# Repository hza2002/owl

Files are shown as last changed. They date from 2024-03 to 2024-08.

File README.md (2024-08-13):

# Owl
**Owl**, an acronym for **Orthogonal Wireless Layout**, combines the ergonomic freedom of wireless connectivity with a split keyboard design influenced by [Lily58](https://github.com/kata0510/Lily58), [Corne](https://github.com/foostan/crkbd), [Sofle](https://github.com/josefadamcik/SofleKeyboard) and [Torn](https://github.com/rtitmuss/torn) keyboards.
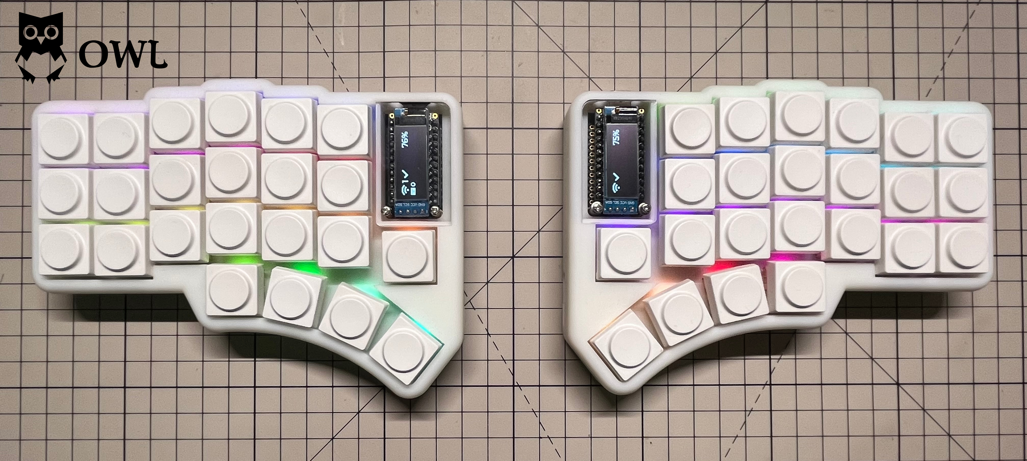
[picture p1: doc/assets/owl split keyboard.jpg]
Owl Split Keyboard

## Feature
- Owl uses **Pro Micro** Interconnect small controller board, which means easy for Maintenance and replacemen. And supports a variety of boards including [nice!nano](https://nicekeyboards.com/nice-nano) and [nrfmicro](https://github.com/joric/nrfmicro/) (I **have not tried yet**, but theoretically feasible).
- Low latency wireless, supported by [ZMK](https://github.com/zmkfirmware/zmk).
- Gorgeous **RGB** lighting effects.
- Two multifunctional **OLED** screens that can display keyboard battery level and connection status.
- Split keyboard conforms to **ergonomics**.
- A total of two PCBs compatible with Cherry MX switches, Kailh choc Low Profile switches, and Gateron Low Profile switches.
- **Double-sided** PCB design, both sides are universal.
## Building your own
Detailed [Build Guide](./doc/build.md).

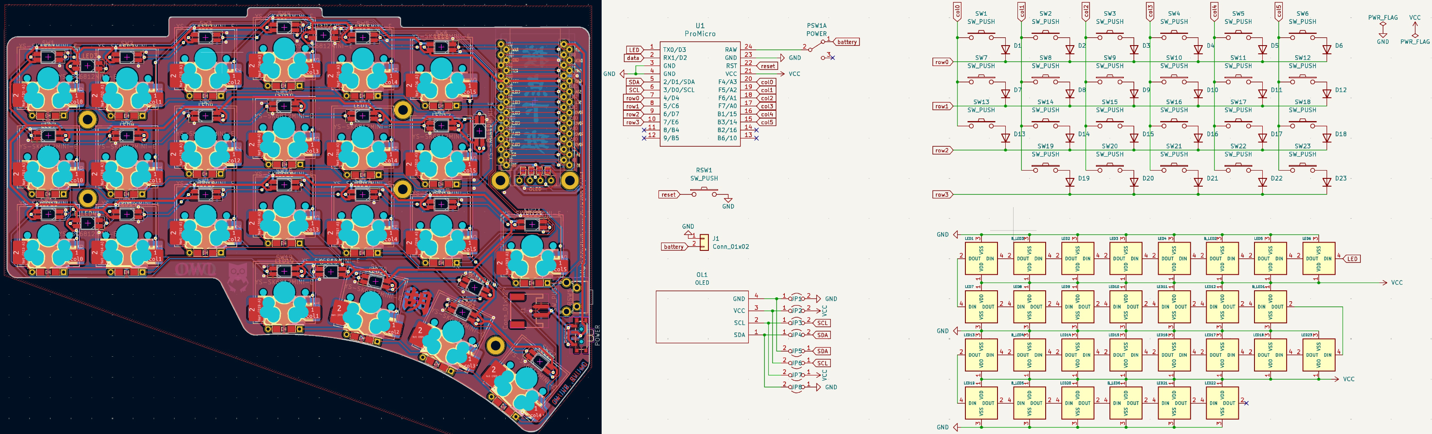
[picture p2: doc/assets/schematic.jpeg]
schematic


Please make sure you can get the ability to build the keyboard:
- Soldering circuit components
- Circuit board production
- 3D printing
- Using GitHub action to build firmware
- Consulting documents carefully
## License


The Owl Keyboard is licensed under [Creative Commons Attribution-NonCommercial 4.0 International License](https://creativecommons.org/licenses/by-nc/4.0).

This PCB design may be freely reproduced, modified, and manufactured for personal use only. If you would like to use this design commercially please contact me at hza2002@foxmail.com to request permission.
## Thanks
I would like to express my sincere gratitude to the creators and contributors of various articles, repositories, and tutorials that greatly contributed to the development of the 'Owl' keyboard. 

These resources provided me with essential insights and knowledge throughout the development process. I am truly thankful for the open-source community's generosity and collaborative spirit."

Without their invaluable resources, this project would not have been possible. I encourage anyone interested in the details of this project to explore the following sources:
### PCB
- [Use KiCad to make PCB - zero-based KiCad Chinese tutorial](https://haipeng.me/2017/03/01/kicad-tutorial/)
- [Kicad advanced tutorial 1: new component](https://haipeng.me/2018/05/24/kicad_advanced_tutorial_1_new_component/)
- [Kicad advanced tutorial 2: new logo](https://haipeng.me/2018/07/11/kicad_advanced_tutorial_2_new_logo/)
- [Kicad advanced tutorial 3: mask opening](https://haipeng.me/2019/09/02/kicad-mask-opening/)
- [How to generate Gerber and Drill files in KiCad 7](https://jlcpcb.com/help/article/362-how-to-generate-gerber-and-drill-files-in-kicad-7)
- [How to generate the BOM and Centroid file from KiCAD](https://jlcpcb.com/help/article/81-How-to-generate-the-BOM-and-Centroid-file-from-KiCAD)
### Other Keyboard
I took inspiration from other keyboards I'd used or liked:
- [Torn](https://github.com/rtitmuss/torn) My first DIY keyboard, easy to build and robust to use. The reason of the Owl keyboard layout (basicly the same).
- [Corne](https://github.com/foostan/crkbd) Handsome and technological design, various styles of PCB provide important reference.
- [Sofle](https://github.com/josefadamcik/SofleKeyboard) Referenced some circuit design and component selection.
- [Lily58](https://github.com/kata0510/Lily58) Referenced some circuit design and component selection.
### helpful repo
- [key-switches.pretty](https://github.com/siderakb/key-switches.pretty) Very helpful. It contains various keyboard footprints and has exquisite instruction tables.
- [keyswitches.pretty](https://github.com/daprice/keyswitches.pretty) KiCAD footprint library for kailh choc and MX-style mechanical switches and their associated sockets.
- [Keebio-Parts.pretty](https://github.com/keebio/Keebio-Parts.pretty) Various KiCAD footprints for mechanical keyboard parts.
## Gallery
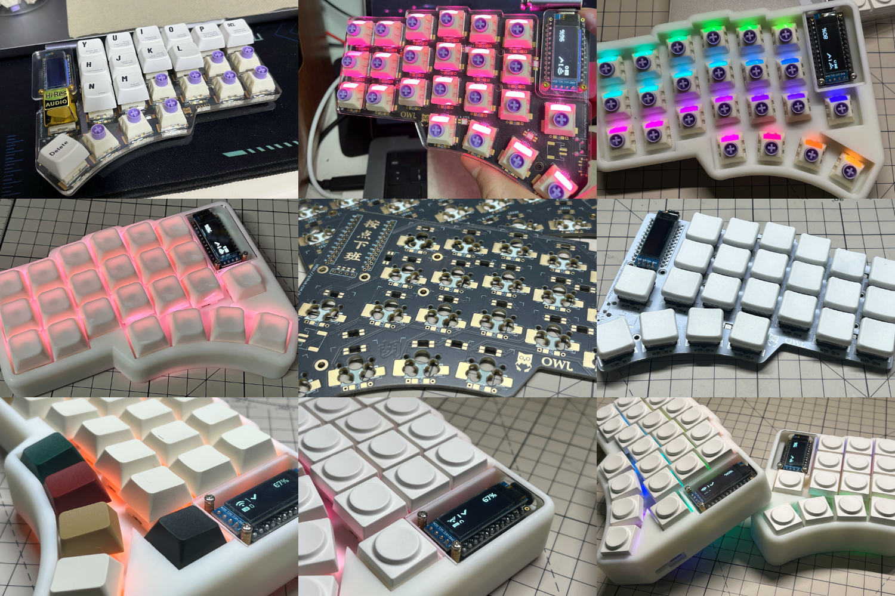
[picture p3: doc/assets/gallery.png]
gallery


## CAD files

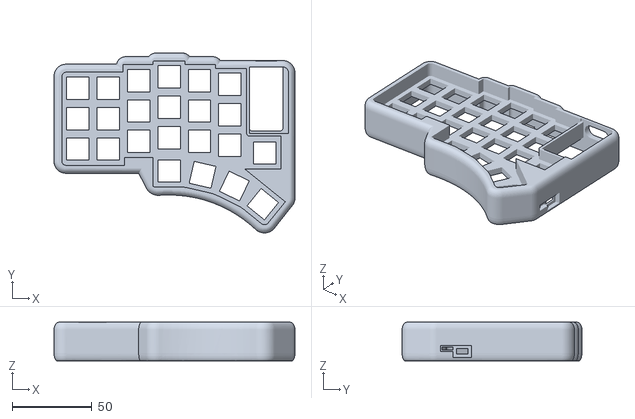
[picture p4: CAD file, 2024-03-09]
case/3D-printed/left.STL
150.7 x 112.5 x 24.3

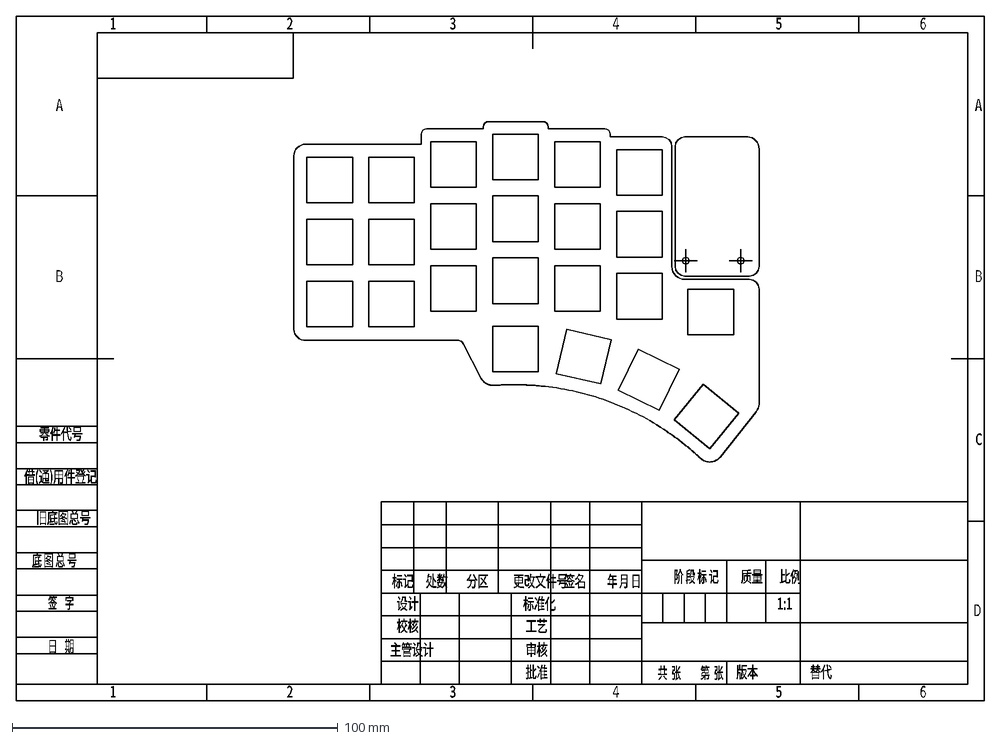
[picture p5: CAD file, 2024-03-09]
case/transparent-explorer/owl-plate.DXF
替代
版本
审核
工艺
比例
质量
第 张
共 张
阶 段 标 记
批准
标准化
主管设计
年 月 日
签名
更改文件号
分区
处数
标记
设计
校核
零件代号
借(通)用件登记
旧底图总号
底 图 总 号
日 期
1:1
1
B
A
D
C
签 字
2
5
4
3
6

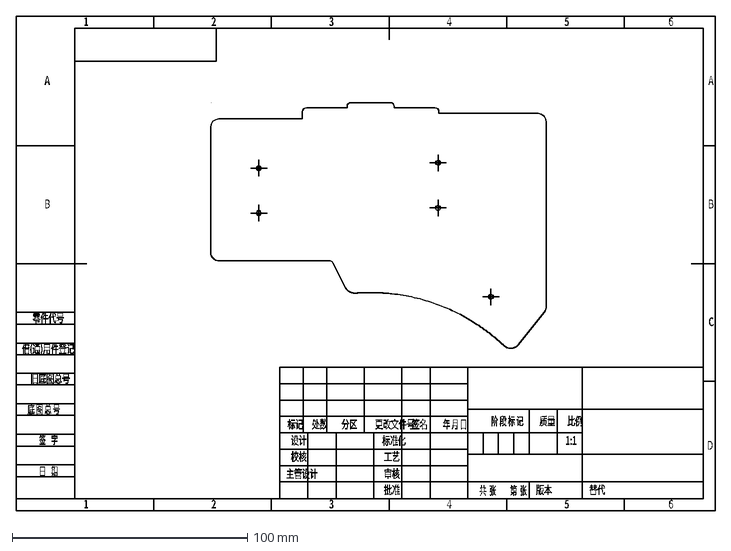
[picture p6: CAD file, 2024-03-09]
case/transparent-explorer/owl-bottom.DXF
替代
版本
审核
工艺
比例
质量
第 张
共 张
阶 段 标 记
批准
标准化
主管设计
年 月 日
签名
更改文件号
分区
处数
标记
设计
校核
零件代号
借(通)用件登记
旧底图总号
底 图 总 号
日 期
1:1
1
B
A
D
C
签 字
2
5
4
3
6

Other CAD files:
case/3D-printed/cover-bottom.DWG
case/3D-printed/right.STL

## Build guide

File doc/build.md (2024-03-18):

# Build Guide
This is the complete construction guide for the Owl keyboard, please read it carefully. If possible, please also refer to other split keyboard construction guides as reference. Please note that if you encounter any difficulties during the installation process, please fully utilize your **DIY abilities** and use various feasible parts. You are free to do so.
## Bill of materials
### Required (PCB)

| Name | Count | Remarks |
| :--- | :---- | :--- |
| PCB | 2 | 1.6mm if use 3D printed case |
| ProMicro | 2 | [nice!nano](https://nicekeyboards.com/nice-nano) |
| Diodes | 46 | SOD-123 or DO-35 |
| Reset switch | 2 | 3\*6\*5 |
| Battery switch | 2 | MSK-1102-1.5H |
| Battery socket | 2 | PH2.0 2P |
| Battery | 2 | 3.7V lithium (max size 40\*50\*70) |
| PCB sockets | 46 | Compatible with MX and Gateron low profile, and Kailh choc if using choc version PCB |
| Key switches | 46 | Only compatible with MX style |
| Keycaps | 46 | 1u cap |

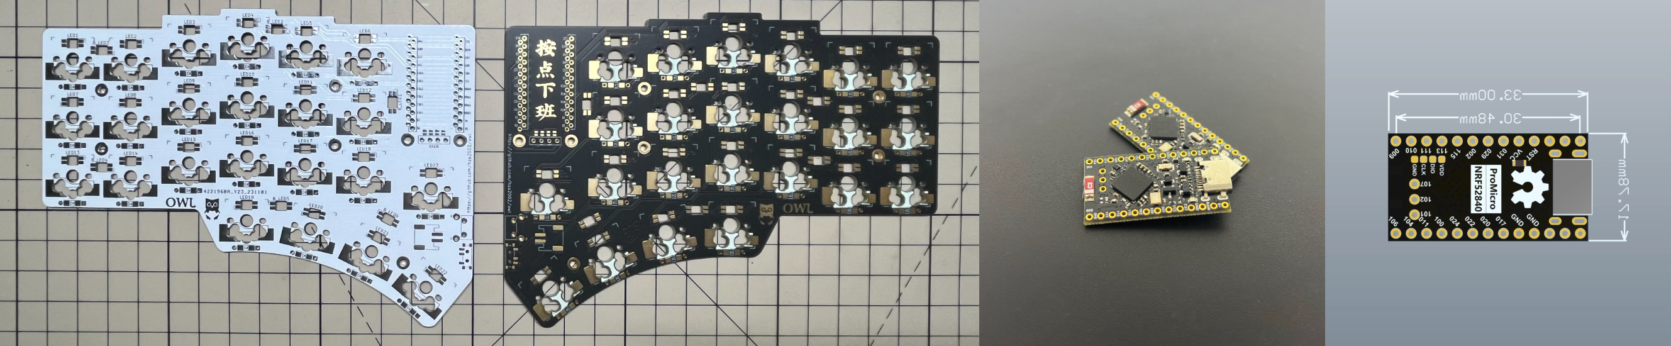
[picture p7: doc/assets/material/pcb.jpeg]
pcb

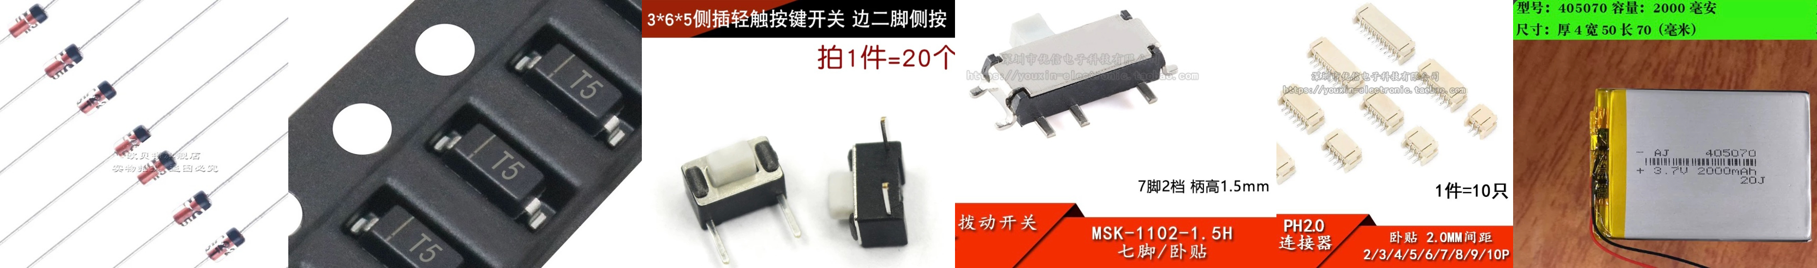
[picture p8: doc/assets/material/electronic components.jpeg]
Electronic components

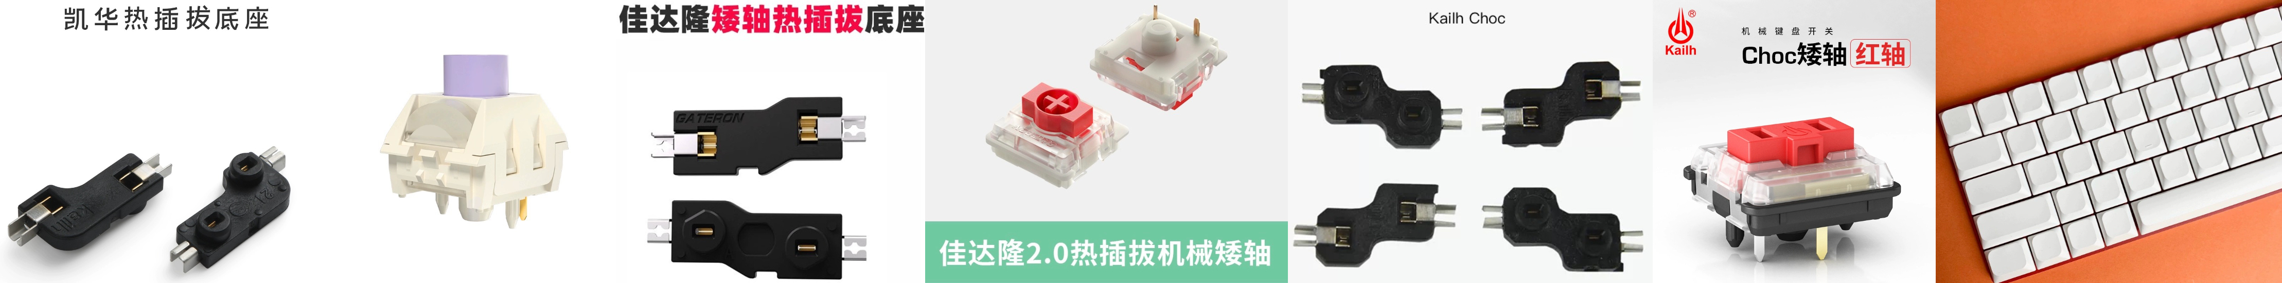
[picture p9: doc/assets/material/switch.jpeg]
switch

### Optional
#### RGB and Oled

| Name | Count | Remarks |
| :--- | :---- | :--- |
| OLED | 2 | 0.91 inches |
| SK6812MINI-E | 58 | Install all lights as they are connected in series |

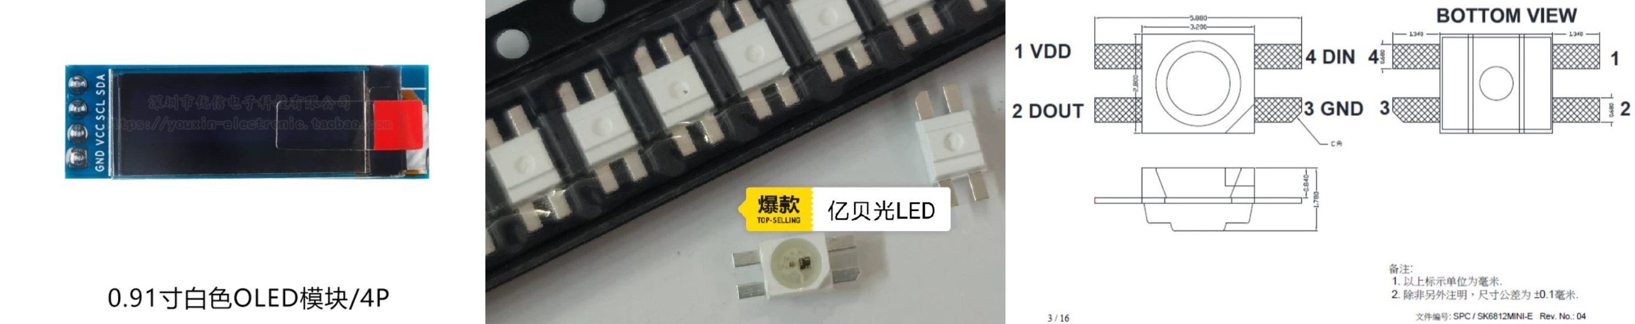
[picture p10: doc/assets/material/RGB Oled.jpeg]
RGB and Oled

#### Case
##### General

| Name | Count | Remarks |
| :--- | :---- | :--- |
| Spacer M2 12mm | 4 | For OLED cover |
| Screw M2 | 24 | At least 3mm |
| Rubber feet | ANY | For anti-slip purposes |

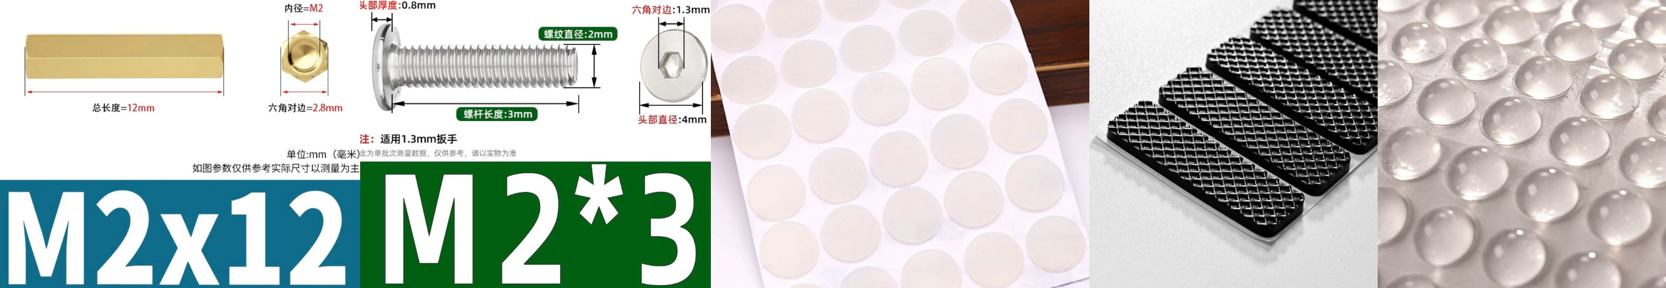
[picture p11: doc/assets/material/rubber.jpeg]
Rubber

##### Transparent-explorer

| Name | Count | Remarks |
| :--- | :---- | :--- |
| Top plate | 2 | 1.5mm-4mm |
| Bottom plate  | 2 | At least 1.5mm |
| OLED cover | 2 | At least 1mm |
| Spacer M2 7mm | 10 | Between pcb and bottom plate |

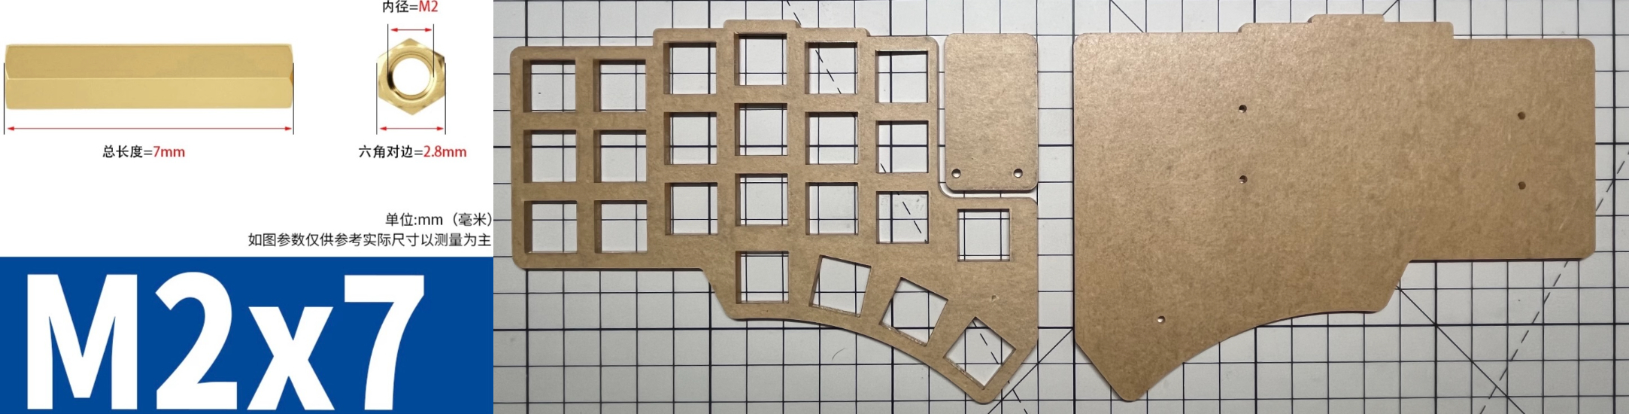
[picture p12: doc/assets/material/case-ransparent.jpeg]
case-transparent

##### 3D-printed

| Name | Count | Remarks |
| :--- | :---- | :--- |
| Spacer M2 7+4mm | 10 | Between pcb and bottom plate |
| Hot melt screw M2\*3\*3.5 | 10 | Used for integrating 3D printed case |
| 3D-printed case<br> | 2 | Please select printing materials freely |
| OLED cover | 2 | 2mm |
| Bottom plate | 2 | 2mm |

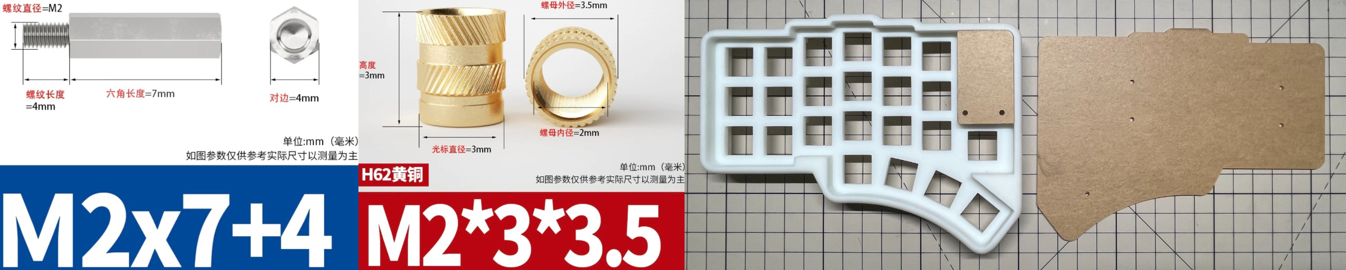
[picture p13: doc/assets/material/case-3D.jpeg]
case-3D

## Assembly
### Switch socket
Please select the corresponding keyboard switch socket according to the selected PCB (**MX switch and Gateron low-profile switch for normal version, MX switch and Kailh low-profile switch for choc version**).

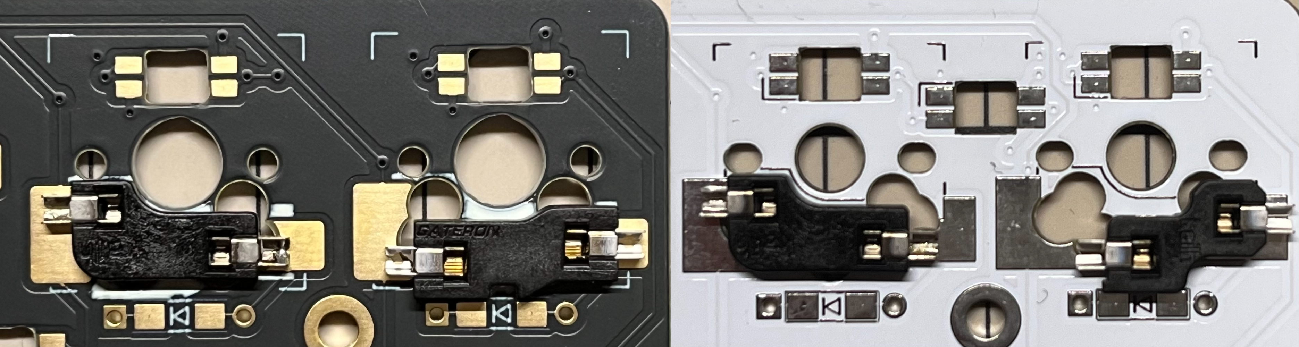
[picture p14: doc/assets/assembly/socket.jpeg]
socket

### RGB light
A single side needs 23 key lights and 6 bottom lights in series, so please install all or none at all. For the convenience of selection and manual soldering, we only use SK6812MINI-E. The position for installing the GND pin has been marked on the PCB. When installing, just pay attention to have the LED facing downwards and the bottom light facing upwards. **They are in opposite directions**.

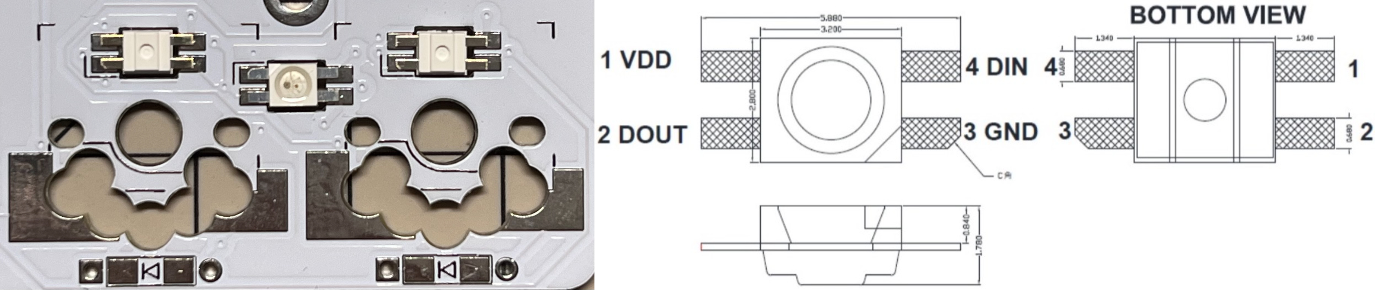
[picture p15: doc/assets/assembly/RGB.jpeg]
RGB

### Diode
Each keyboard switch corresponds to a diode. You can freely choose between surface-mount diodes or through-hole diodes, and even install them on the front or back of the PCB (note that installing on the back **may conflict** with the case). In any case, **please make sure that the direction of the diode is correct**.

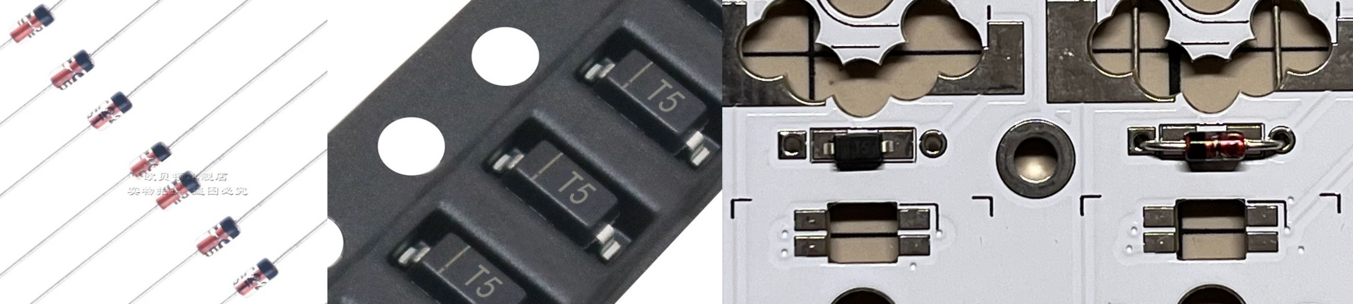
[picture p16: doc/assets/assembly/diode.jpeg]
diode

### Switch and Battery
The reset and boot switches, as well as the power socket, are very easy to solder. It is not necessary to elaborate here. It is worth noting that the protruding pins on the back of the straight plug switch should be polished and trimmed to avoid affecting the installation of the housing. **Please be careful to pay attention to the battery wire sequence**.

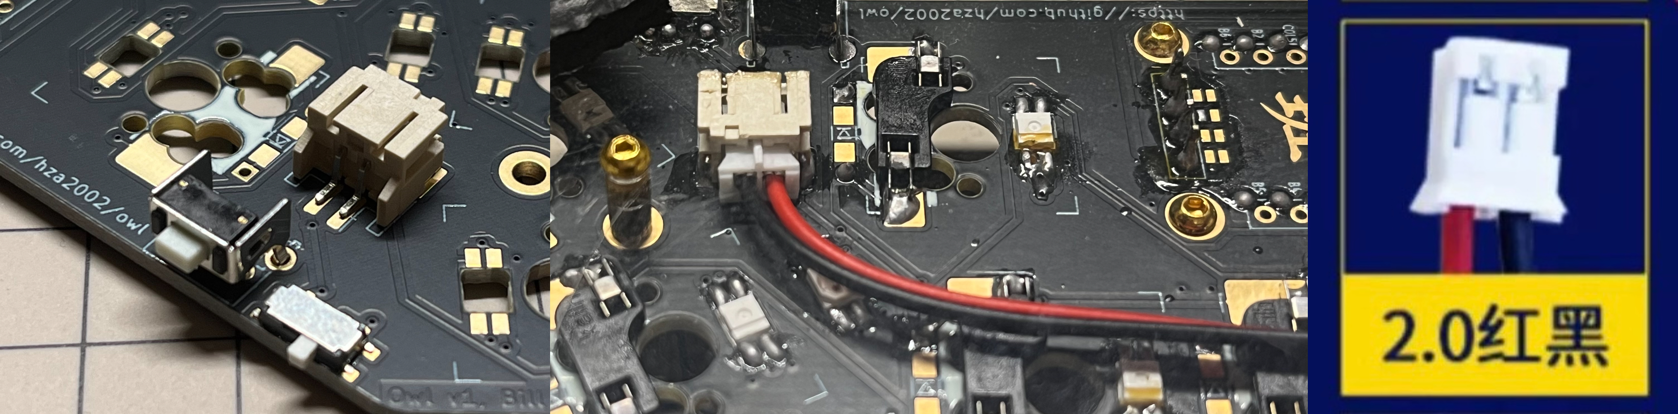
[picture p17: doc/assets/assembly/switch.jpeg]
switch

### Chip and Oled
Since the PCB is double-sided, you can install the chip on either side, whether it is directly soldered or connected with a socket. The position where the chip pins should be installed is marked on each side, be careful not to solder incorrectly.

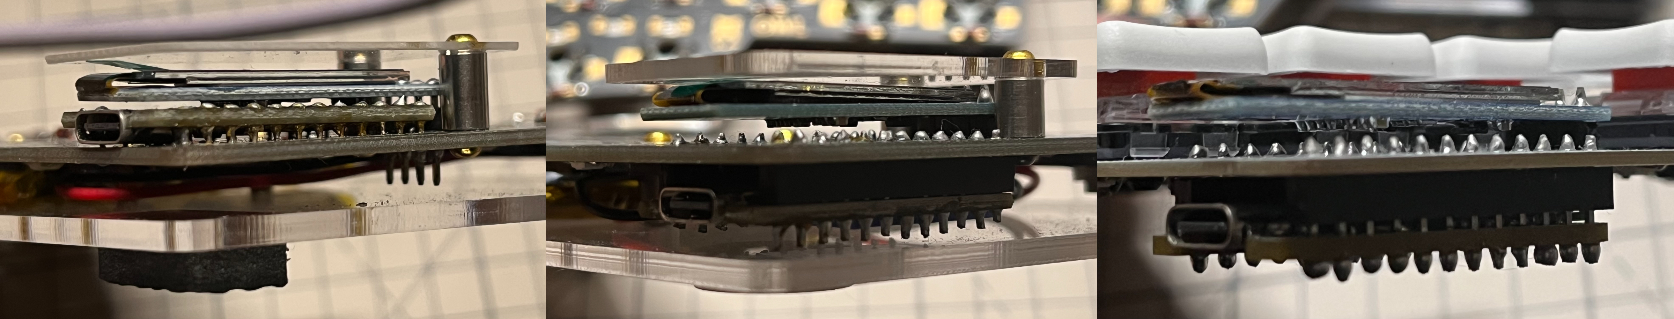
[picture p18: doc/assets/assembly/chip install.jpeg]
chip install

**If you want to use 3D printed shell, be sure to follow the steps below!**

recommand chip install
It is recommended to use the low-profile slot to install the chip on the front of the keyboard. Pay attention to installing the slot on the column marked on the PCB. When installing the chip, make sure that its back side (the flat side without components) faces up. Finally, when installing the OLED screen, please make sure they are installed tightly.
### Case
#### 3D-printed
First, install five hot-melt screws into the 3D printed case, then place the completed PCB inside, tighten the five screws, and finally install the back panel and front OLED acrylic.

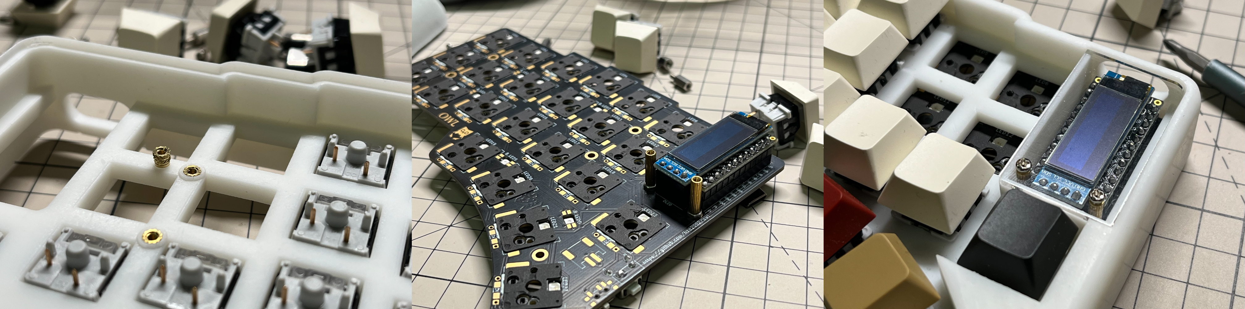
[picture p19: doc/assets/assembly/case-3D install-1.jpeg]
3D-printed case install1

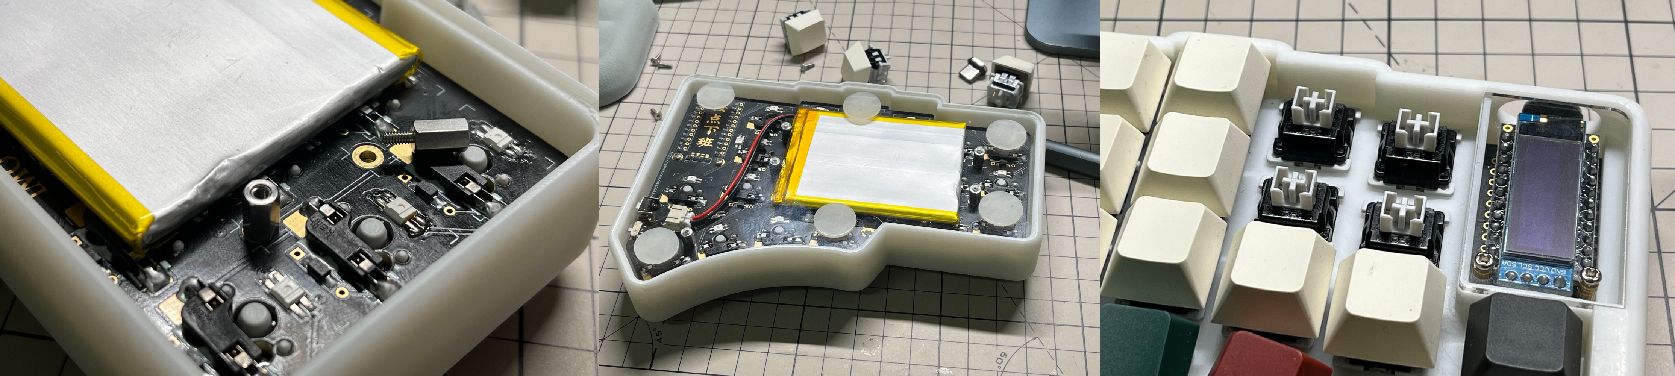
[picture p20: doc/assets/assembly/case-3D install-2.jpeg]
3D-printed case install2

#### transparent explorer
This case does not have much to pay attention to, only using m2 screws and two-stage screws for connection.

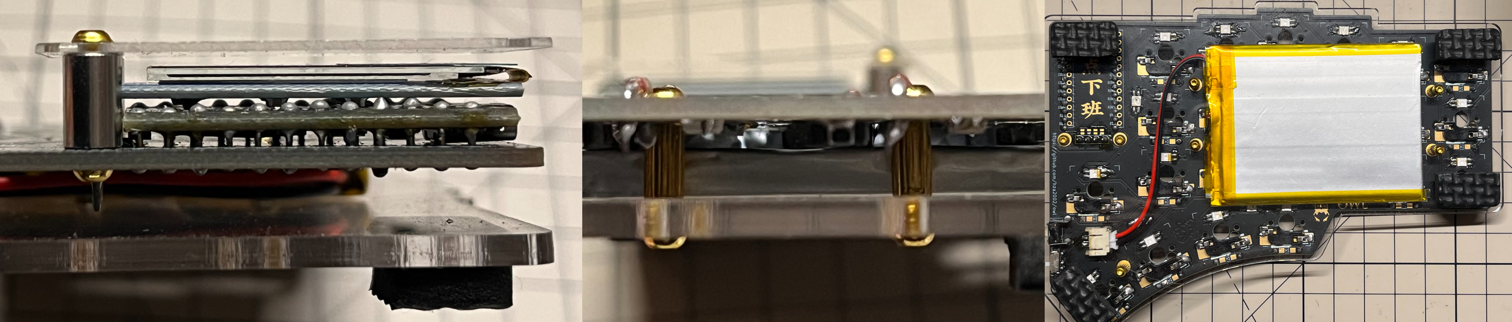
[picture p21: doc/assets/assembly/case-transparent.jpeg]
transparent case

### Key
The final step is to install the keyboard switches and keycaps, just align them, very simple, please feel free to use your creativity to mix and match.

## Firmware
This keyboard uses ZMK as firmware, please refer to my [zmk-config](https://github.com/hza2002/zmk-config) repository.

The method of flashing firmware is very simple. Just press the boot button twice quickly to enter boot mode, and the keyboard controller will appear on the computer like a USB flash drive. Drag and drop the firmware to update it.

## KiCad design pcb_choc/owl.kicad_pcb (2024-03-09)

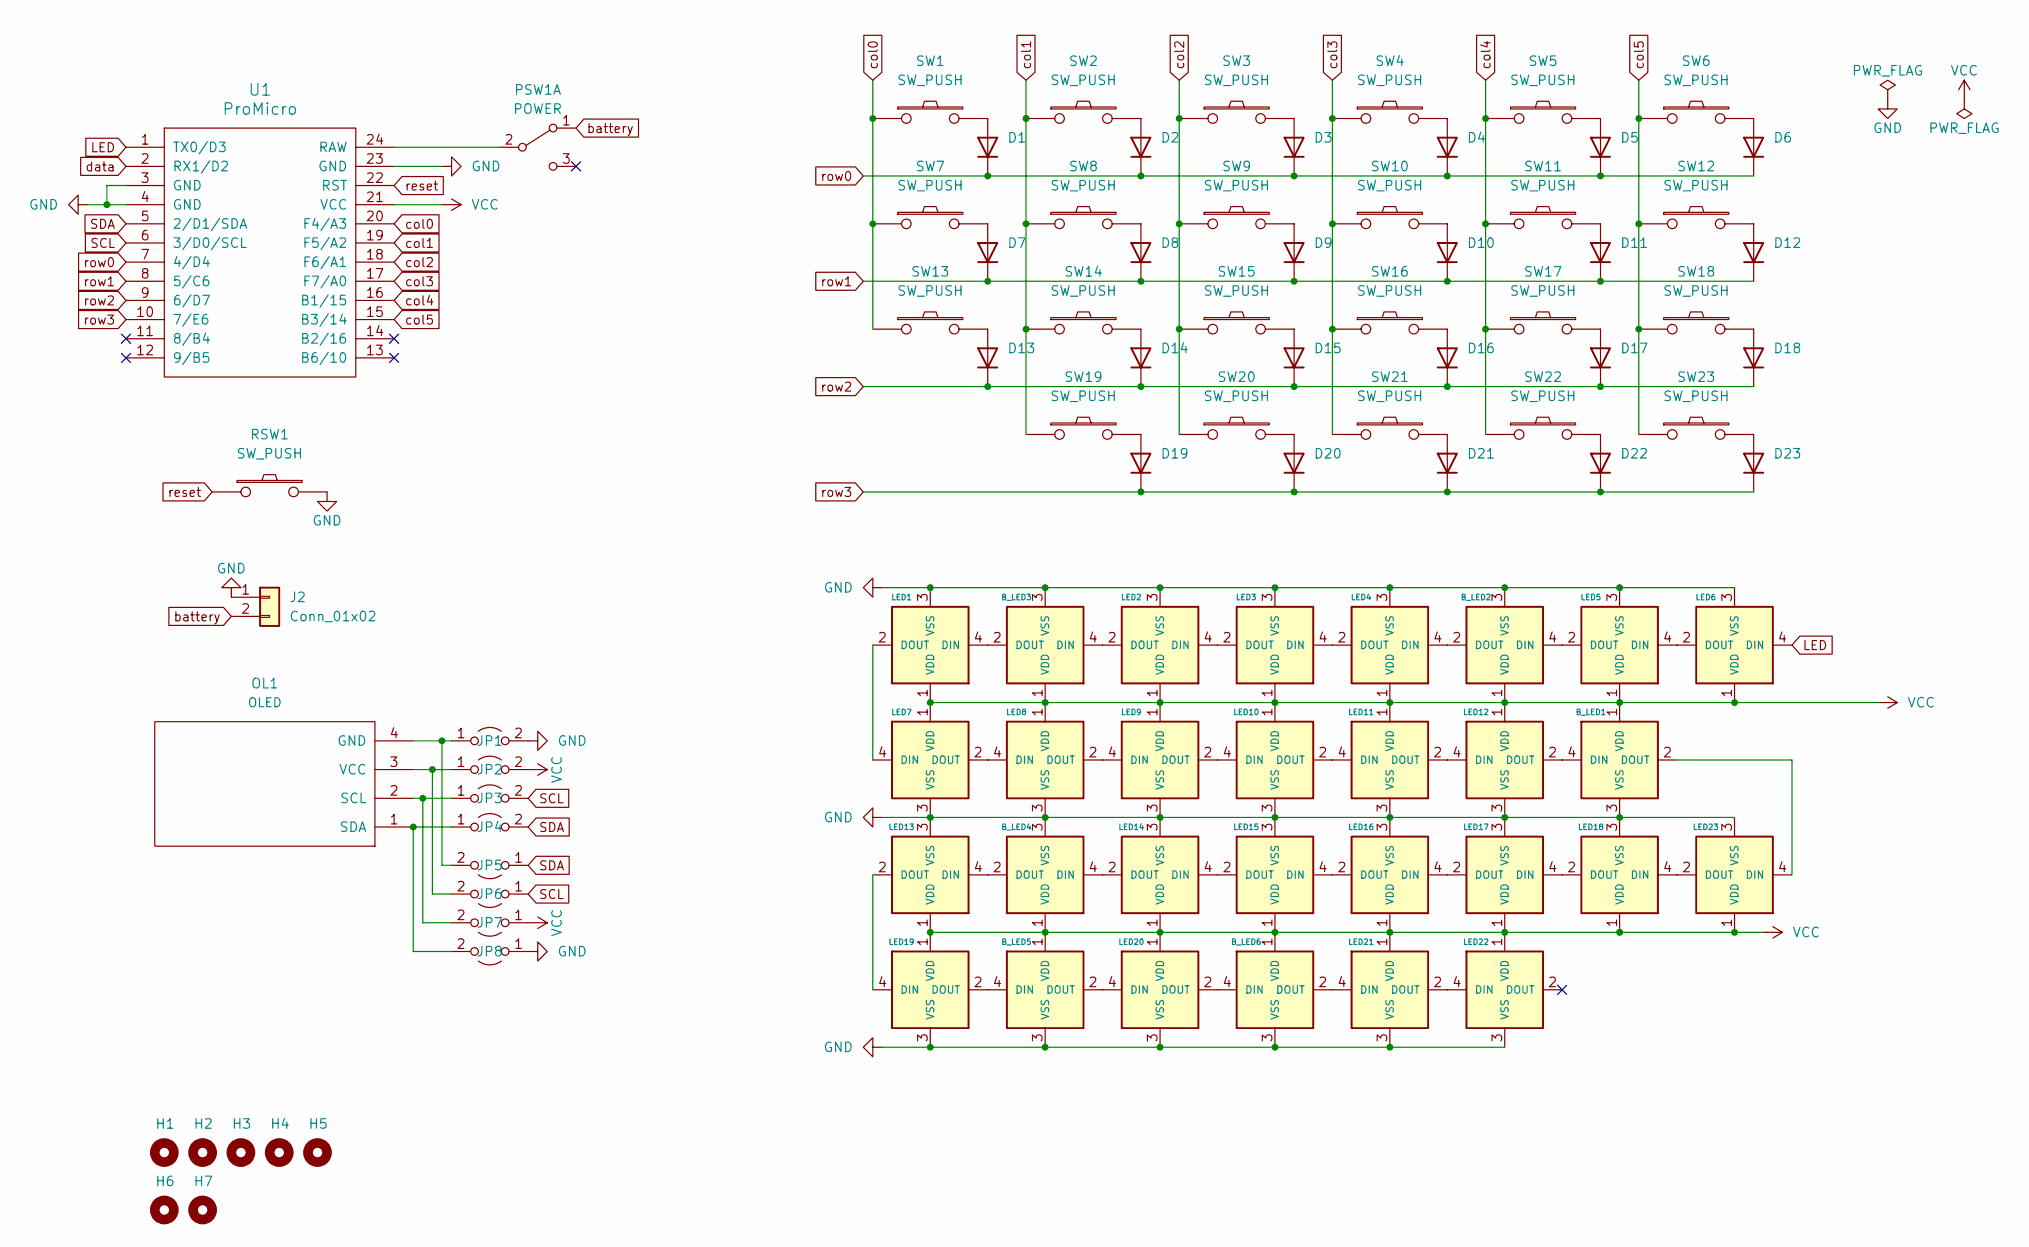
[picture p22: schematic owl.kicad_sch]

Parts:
B_LED1, B_LED2, B_LED3, B_LED4, B_LED5, B_LED6: YS-SK6812MINI-E; YS-SK6812MINI-E_Back_Rev
D1, D2, D3, D4, D5, D6, D7, D8, D9, D10, D11, D12, D13, D14, D15, D16, D17, D18, D19, D20, D21, D22, D23: D; Diode_TH_SMD_Rev
H1, H2, H3, H4, H5, H6, H7: MountingHole; M2_Hole_TH
J2: Conn_01x02; JST_PH_S2B-PH-SM4-TB_1x02-1MP_P2.00mm_Horizontal
JP1, JP2, JP3, JP4, JP5, JP6, JP7, JP8: Jumper_2_Open; Jumper
LED1, LED2, LED3, LED4, LED5, LED6, LED7, LED8, LED9, LED10, LED11, LED12, LED13, LED14, LED15, LED16, LED17, LED18, LED19, LED20, LED21, LED22, LED23: YS-SK6812MINI-E; YS-SK6812MINI-E_Rev
OL1: OLED; OLED_4Pin_Rev
PSW1: POWER; SW_SPDT_PCM12_Rev
RSW1: SW_PUSH; SW_Tactile_SPST_Angled_PTS645Vx39-2LFS_Rev
SW1, SW2, SW3, SW4, SW5, SW6, SW7, SW8, SW9, SW10, SW11, SW12, SW13, SW14, SW15, SW16, SW17, SW18, SW19, SW20, SW21, SW22, SW23: SW_PUSH; SW_MX_Choc_HotSwap_double
U1: ProMicro; ProMicro_Rev

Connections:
GND: B_LED1.3 (VSS), B_LED2.3 (VSS), B_LED3.3 (VSS), B_LED4.3 (VSS), B_LED5.3 (VSS), B_LED6.3 (VSS), JP1.2 (B), JP8.1 (A), LED1.3 (VSS), LED2.3 (VSS), LED3.3 (VSS), LED4.3 (VSS), LED5.3 (VSS), LED6.3 (VSS), LED7.3 (VSS), LED8.3 (VSS), LED9.3 (VSS), LED10.3 (VSS), LED11.3 (VSS), LED12.3 (VSS), LED13.3 (VSS), LED14.3 (VSS), LED15.3 (VSS), LED16.3 (VSS), LED17.3 (VSS), LED18.3 (VSS), LED19.3 (VSS), LED20.3 (VSS), LED21.3 (VSS), LED22.3 (VSS), LED23.3 (VSS), RSW1.2, U1.3 (GND), U1.4 (GND), U1.23 (GND); also elsewhere on the board
LED: LED6.4 (DIN), U1.1 (TX0/D3)
unnamed: B_LED1.4 (DIN), LED12.2 (DOUT)
unnamed: B_LED1.2 (DOUT), LED23.4 (DIN)
unnamed: B_LED2.4 (DIN), LED5.2 (DOUT)
unnamed: B_LED2.2 (DOUT), LED4.4 (DIN)
unnamed: B_LED3.4 (DIN), LED2.2 (DOUT)
unnamed: B_LED3.2 (DOUT), LED1.4 (DIN)
unnamed: B_LED4.4 (DIN), LED14.2 (DOUT)
unnamed: B_LED4.2 (DOUT), LED13.4 (DIN)
unnamed: B_LED5.4 (DIN), LED19.2 (DOUT)
unnamed: B_LED5.2 (DOUT), LED20.4 (DIN)
unnamed: B_LED6.4 (DIN), LED20.2 (DOUT)
unnamed: B_LED6.2 (DOUT), LED21.4 (DIN)
unnamed: D1.2 (A), SW1.2
unnamed: D2.2 (A), SW2.2
unnamed: D3.2 (A), SW3.2
unnamed: D4.2 (A), SW4.2
unnamed: D5.2 (A), SW5.2
unnamed: D6.2 (A), SW6.2
unnamed: D7.2 (A), SW7.2
unnamed: D8.2 (A), SW8.2
unnamed: D9.2 (A), SW9.2
unnamed: D10.2 (A), SW10.2
unnamed: D11.2 (A), SW11.2
unnamed: D12.2 (A), SW12.2
unnamed: D13.2 (A), SW13.2
unnamed: D14.2 (A), SW14.2
unnamed: D15.2 (A), SW15.2
unnamed: D16.2 (A), SW16.2
unnamed: D17.2 (A), SW17.2
unnamed: D18.2 (A), SW18.2
unnamed: D19.2 (A), SW19.2
unnamed: D20.2 (A), SW20.2
unnamed: D21.2 (A), SW21.2
unnamed: D22.2 (A), SW22.2
unnamed: D23.2 (A), SW23.2
unnamed: JP1.1 (A), JP5.2 (B), OL1.4 (GND)
unnamed: JP2.1 (A), JP6.2 (B), OL1.3 (VCC)
unnamed: JP3.1 (A), JP7.2 (B), OL1.2 (SCL)
unnamed: JP4.1 (A), JP8.2 (B), OL1.1 (SDA)
unnamed: LED1.2 (DOUT), LED7.4 (DIN)
unnamed: LED2.4 (DIN), LED3.2 (DOUT)
unnamed: LED3.4 (DIN), LED4.2 (DOUT)
unnamed: LED5.4 (DIN), LED6.2 (DOUT)
unnamed: LED7.2 (DOUT), LED8.4 (DIN)
unnamed: LED8.2 (DOUT), LED9.4 (DIN)
unnamed: LED9.2 (DOUT), LED10.4 (DIN)
unnamed: LED10.2 (DOUT), LED11.4 (DIN)
unnamed: LED11.2 (DOUT), LED12.4 (DIN)
unnamed: LED13.2 (DOUT), LED19.4 (DIN)
unnamed: LED14.4 (DIN), LED15.2 (DOUT)
unnamed: LED15.4 (DIN), LED16.2 (DOUT)
unnamed: LED16.4 (DIN), LED17.2 (DOUT)
unnamed: LED17.4 (DIN), LED18.2 (DOUT)
unnamed: LED18.4 (DIN), LED23.2 (DOUT)
unnamed: LED21.2 (DOUT), LED22.4 (DIN)
unnamed: PSW1.2 (B), U1.24 (RAW)
SCL: JP3.2 (B), JP6.1 (A), U1.6 (3/D0/SCL)
SDA: JP4.2 (B), JP5.1 (A), U1.5 (2/D1/SDA)
VCC: B_LED1.1 (VDD), B_LED2.1 (VDD), B_LED3.1 (VDD), B_LED4.1 (VDD), B_LED5.1 (VDD), B_LED6.1 (VDD), JP2.2 (B), JP7.1 (A), LED1.1 (VDD), LED2.1 (VDD), LED3.1 (VDD), LED4.1 (VDD), LED5.1 (VDD), LED6.1 (VDD), LED7.1 (VDD), LED8.1 (VDD), LED9.1 (VDD), LED10.1 (VDD), LED11.1 (VDD), LED12.1 (VDD), LED13.1 (VDD), LED14.1 (VDD), LED15.1 (VDD), LED16.1 (VDD), LED17.1 (VDD), LED18.1 (VDD), LED19.1 (VDD), LED20.1 (VDD), LED21.1 (VDD), LED22.1 (VDD), LED23.1 (VDD), U1.21 (VCC)
battery: PSW1.1 (A); also elsewhere on the board
col0: SW1.1, SW7.1, SW13.1, U1.20 (F4/A3)
col1: SW2.1, SW8.1, SW14.1, SW19.1, U1.19 (F5/A2)
col2: SW3.1, SW9.1, SW15.1, SW20.1, U1.18 (F6/A1)
col3: SW4.1, SW10.1, SW16.1, SW21.1, U1.17 (F7/A0)
col4: SW5.1, SW11.1, SW17.1, SW22.1, U1.16 (B1/15)
col5: SW6.1, SW12.1, SW18.1, SW23.1, U1.15 (B3/14)
data: U1.2 (RX1/D2)
reset: RSW1.1, U1.22 (RST)
row0: D1.1 (K), D2.1 (K), D3.1 (K), D4.1 (K), D5.1 (K), D6.1 (K), U1.7 (4/D4)
row1: D7.1 (K), D8.1 (K), D9.1 (K), D10.1 (K), D11.1 (K), D12.1 (K), U1.8 (5/C6)
row2: D13.1 (K), D14.1 (K), D15.1 (K), D16.1 (K), D17.1 (K), D18.1 (K), U1.9 (6/D7)
row3: D19.1 (K), D20.1 (K), D21.1 (K), D22.1 (K), D23.1 (K), U1.10 (7/E6)

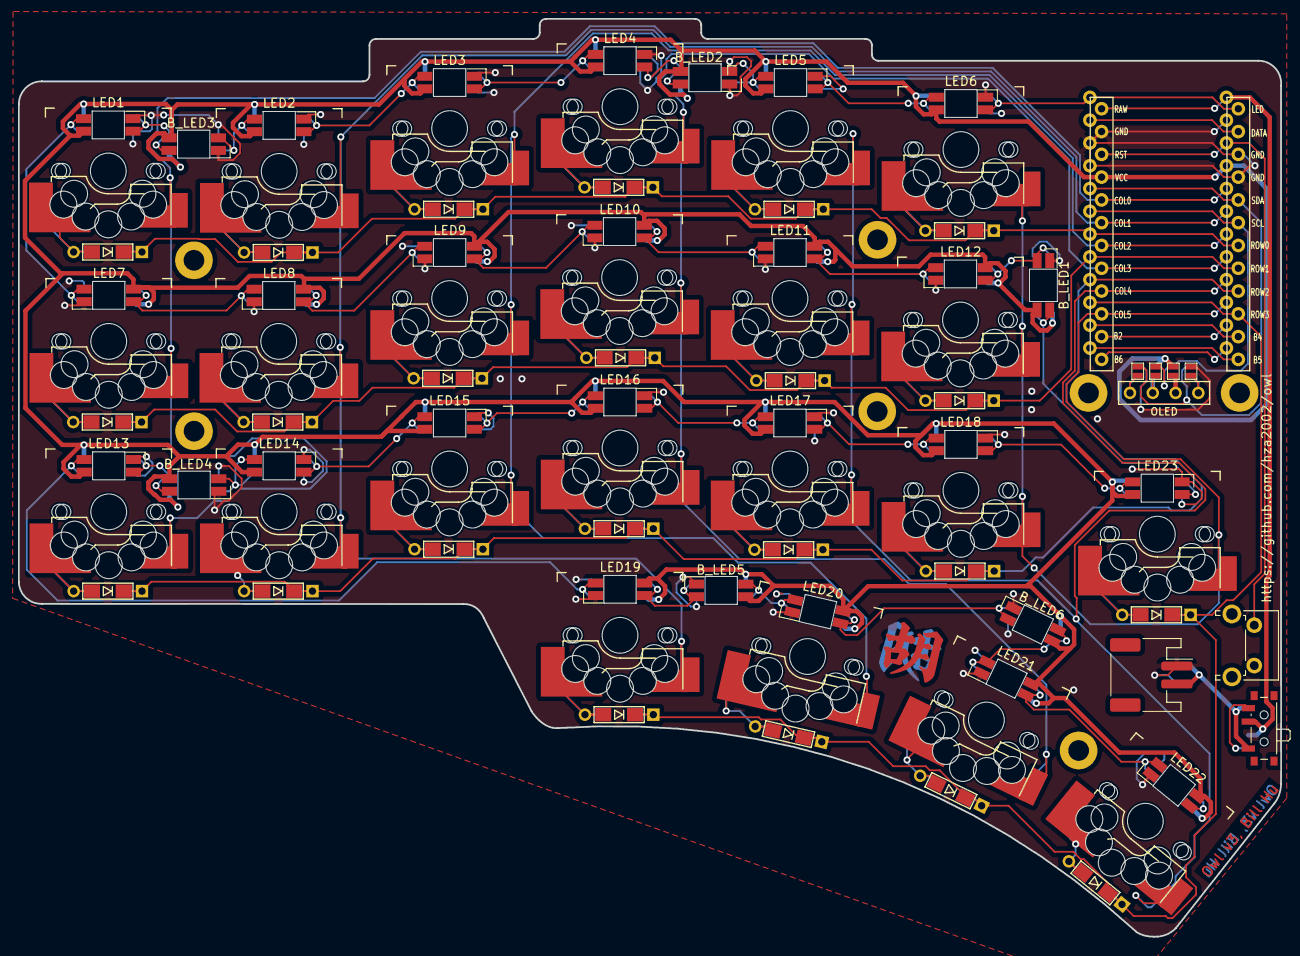
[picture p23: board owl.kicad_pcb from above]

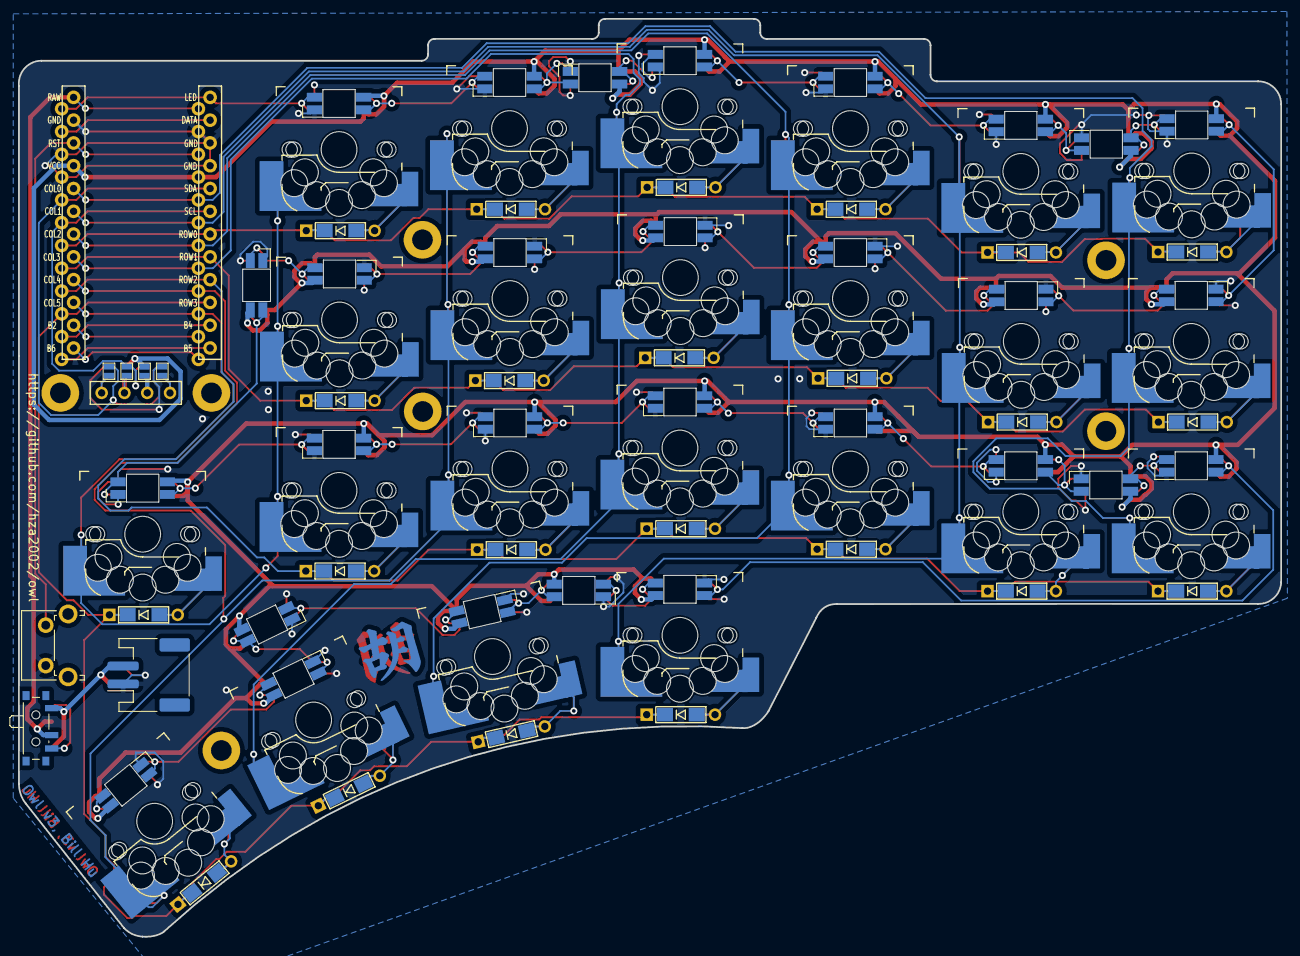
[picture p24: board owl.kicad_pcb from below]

Board: 2 copper layers, 140.7 x 102.3 mm, 97 parts (6 on the bottom side), 73 nets.

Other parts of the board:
J1: Conn_01x02; JST_PH_S2B-PH-SM4-TB_1x02-1MP_P2.00mm_Horizontal
logo: LOGO; owl_logo
logo#2: LOGO; owl_logo

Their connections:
GND: J1.1; also elsewhere on the board
battery: J1.2; also elsewhere on the board

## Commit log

2024-03-09 Add pcb and case
    [cover-bottom.DWG, left.STL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]
2024-03-15 Complete doc except 3D-printed case and chip install
2024-03-18 Finish 3D-printed case install tutorial
